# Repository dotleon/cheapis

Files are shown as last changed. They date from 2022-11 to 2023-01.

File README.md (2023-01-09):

# cheapis

v0.1 issues:
- most ubs cables cannot be plugged in when the pro micro is soldered in an usual way (upright, with the usually included pins), because of the top middle buttons. It has to be solderes upside down, flush with the keyboard pcb.
- not really an issue, but SOD-323 diodes are challenging to solder. They're also not the cheapest, although the difference is minuscule.

Cheapis was inspired by ferris and sweep.

It is the cheapest alternative to the above keyboards (that still has a PCB) as it is sub 100x100mm in size so it can be ordered for a very low price and it only needs one controller (Pro Micro or alternative).

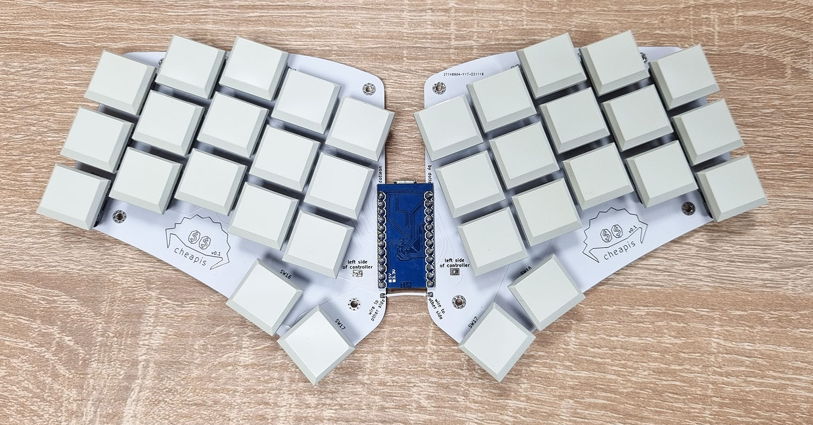
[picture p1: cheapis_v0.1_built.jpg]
cheapis keyboard! cheapis keyboard built


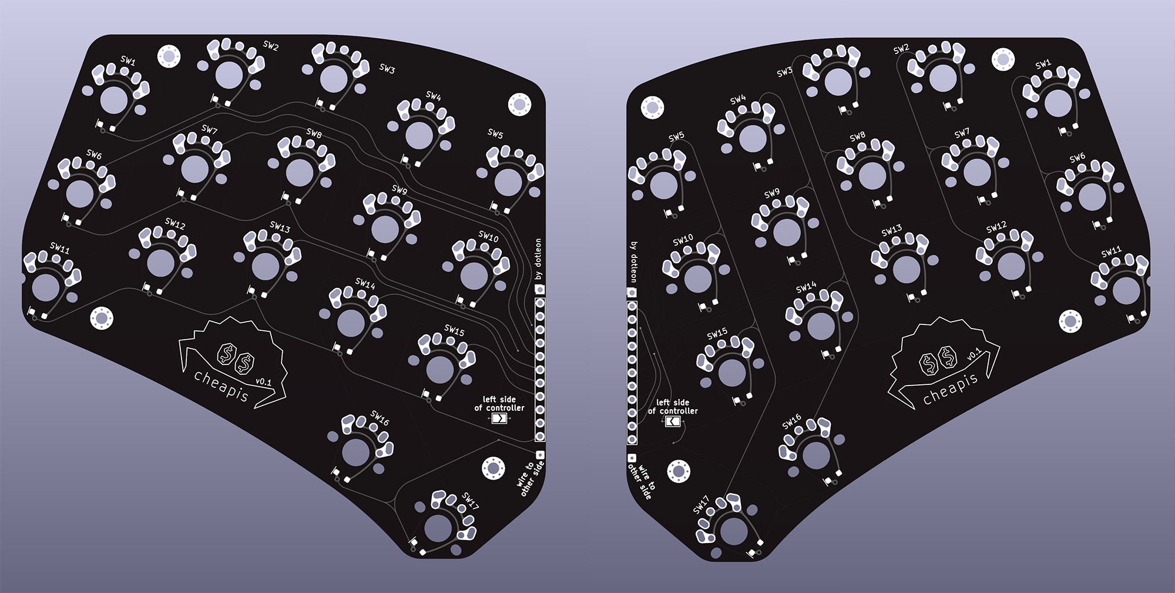
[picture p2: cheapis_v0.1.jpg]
cheapis keyboard! cheapis keyboard


Specs:
- Split
- Unibody
- 34 key
- Compatible with MX, Kailh Choc v1 and Gateron low profile switches
- needs 1n4148 SOD-323 diodes
- 19mm standard spacing
- angled sides by 20 degree

Pros:
- less than 100x100mm
- reversible, so you can order less
- needs ony one Pro Micro or alternative
- very cheap way to experiment with 34 key layout

Cons:
- it has to be unibody
- tenting is not possible
- fragile without a plate as the Pro Micro keeps the two sides together
- not much features, it's hardly more than a hardwire

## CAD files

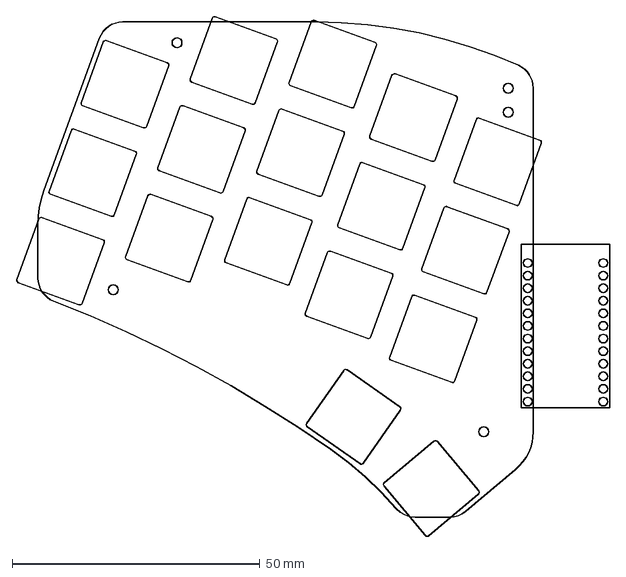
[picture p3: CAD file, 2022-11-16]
v0.1/design.dxf
119.6 x 104.9 mm

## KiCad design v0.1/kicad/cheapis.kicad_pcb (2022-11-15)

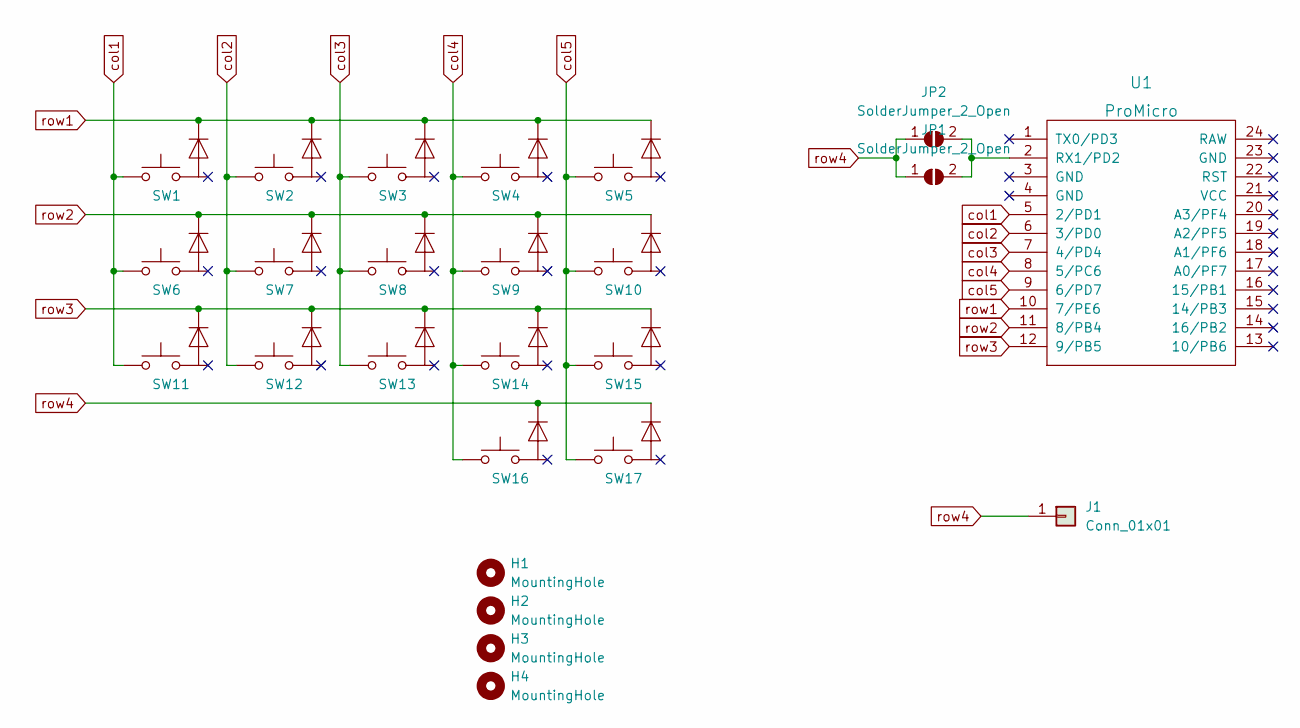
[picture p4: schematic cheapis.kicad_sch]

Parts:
H1, H2, H3, H4: MountingHole; MountingHole_2.2mm_M2_Pad_Via
J1: Conn_01x01; SolderWire-0.1sqmm_1x01_D0.4mm_OD1mm
JP1, JP2: SolderJumper_2_Open; SolderJumper-2_P1.3mm_Open_TrianglePad1.0x1.5mm
SW1, SW2, SW3, SW4, SW5, SW6, SW7, SW8, SW9, SW10, SW12, SW13, SW14, SW15, SW16, SW17: SW_Diode_Combined; SW_MX_GATLP_CHOC_reversible
SW11: SW_Diode_Combined; SW_MX_GATLP_CHOC_reversible_sideofpcb
U1: ProMicro; promicro_half

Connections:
unnamed: JP1.2 (B), JP2.2 (B), U1.2 (RX1/PD2)
col1: SW1.1, SW6.1, SW11.1, U1.5 (2/PD1)
col2: SW2.1, SW7.1, SW12.1, U1.6 (3/PD0)
col3: SW3.1, SW8.1, SW13.1, U1.7 (4/PD4)
col4: SW4.1, SW9.1, SW14.1, SW16.1, U1.8 (5/PC6)
col5: SW5.1, SW10.1, SW15.1, SW17.1, U1.9 (6/PD7)
row1: SW1.3, SW2.3, SW3.3, SW4.3, SW5.3, U1.10 (7/PE6)
row2: SW6.3, SW7.3, SW8.3, SW9.3, SW10.3, U1.11 (8/PB4)
row3: SW11.3, SW12.3, SW13.3, SW14.3, SW15.3, U1.12 (9/PB5)
row4: J1.1, JP1.1 (A), JP2.1 (A), SW16.3, SW17.3

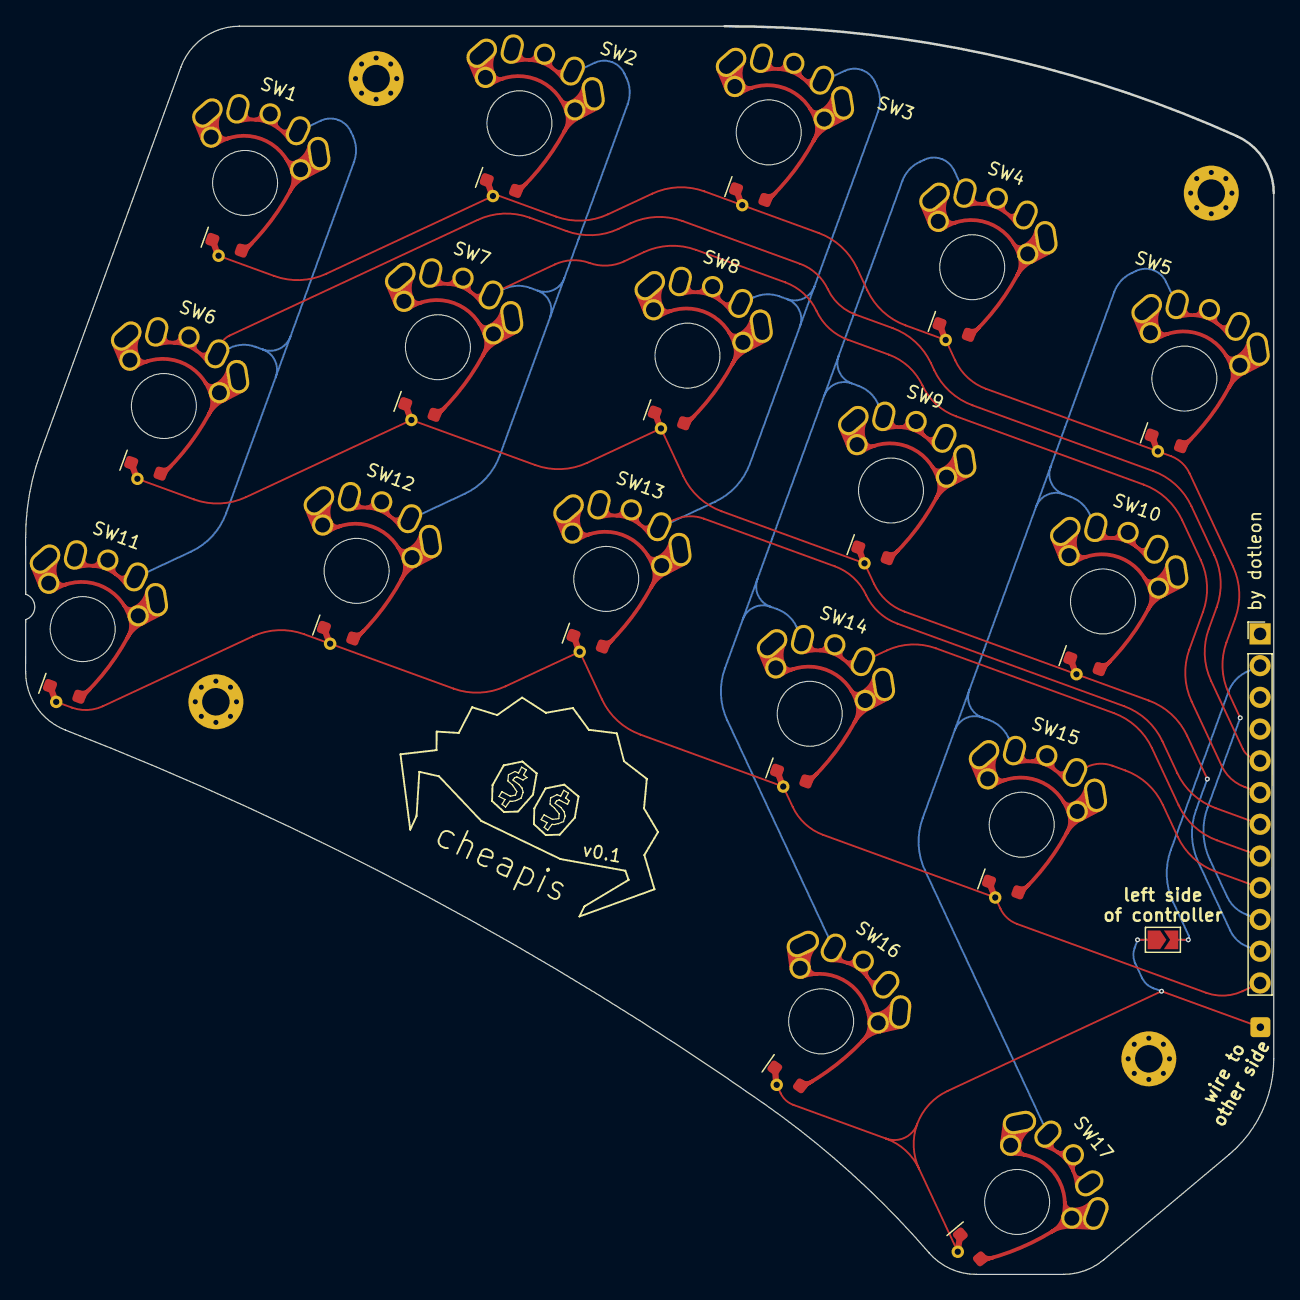
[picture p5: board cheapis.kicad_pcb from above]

Board: 2 copper layers, 99.9 x 99.9 mm, 25 parts (1 on the bottom side), 10 nets.

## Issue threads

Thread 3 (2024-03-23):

Build guide

ohri-anurag, 2024-03-23:
Hi there, thanks a lot for creating this keyboard! I've ordered parts for it, and I wanted to clarify some questions that I had:
1. Can I use Cherry low profile switches?
2. Could you upload another pic of the fully built keyboard, but one from the back? It would answer most questions that I have. I'm a bit confused about how to solder the MCU and diodes. If not a pic, then a line or two about orientation would help greatly.

dotleon, 2024-03-23:
Hey,

I'm a little bit ashamed that this got traction, as v0.1 is a little bit jank. In the future I'm planning on making a better version (better diode support, better ways to mount the controller).

1. As far as I know, Cherry MXLP has the same footprint as MX, so it should be fine.
2. Here I made a video for you about the controller, and the diodes go under the keys, where leds would go.
https://www.youtube.com/watch?v=thpRRhPbJ5U

ohri-anurag, 2024-03-23:
Thanks, that clarifies the questions I had about the MCU. When you say the diodes go under the keys, do you mean that both of them are soldered on the same side of the PCB?

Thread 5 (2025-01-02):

Question regarding the cable

thomas88100, 2025-01-02:
Hi,
I'm new in the world of split diy keyboards and I want to know what type of wire I can use to connect the two parts ? Is it just a simple electric wire ?

dotleon, 2025-01-02:
Hey,

Yes, you can use any electic wire. I've used wire salvaged from an ethernet cable.

Closed 2025-02-03.

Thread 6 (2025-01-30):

Would a diode-less design be possible?

ashok-arora, 2025-01-30:
Hey, thank you for the design! It is very neat. Since diodes are hard to solder and there are a lot of them, would a diode-less design be possible?

dotleon, 2025-01-30:
Not really, you would have to short the two pads where the diodes go. You might be able to do that with solder, but I usually struggle bridging even smaller distances.
A new version would be in order, with THT diode, diode-less, etc support, but as I didn't get into 34 keys, it's hard to find the motivation.

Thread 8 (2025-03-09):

Usb placement problem

Apiratchai, 2025-03-09:
Hello, I really like this project and also working on a fork that will use the Redragon low profile switch instead.

You stated in your reddit post that v0.2 will solve the usb placement problem, how would it look like ?

dotleon, 2025-03-09:
Hello.

There is a lot of extra empty space in the 100x100 rectangle (green) which could be used for an extra break-off part which would go between the two sides.
This would solve a couple of things:

- It could use more pins for better stability, especially because of having more than one column
- as you have two of these per keyboard, you could use both, one over and one under the pcb for even more stability
- the extra wire and the jumper pad wouldn't be necessary as the controller could be routed properly on this extra board
- but most importantly it would increase the distance between the two halves, therefore there would be enough space for the USB

One big disadvantage is that JLCPCB could recognize this as two designs and charge extra for it.

Here's what I imagined:

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

Apiratchai, 2025-03-09:
That’s a brilliant.
I’m wondering if we could route some open wires that don’t actually serve any purpose to the breakout part, just to trick them into thinking they’re part of the thumb cluster. It's similar to how the Corne 5x6 layout can be broken down into a 5x5 layout. The Corne uses M3 screw holes as a break point for that.

dotleon, 2025-03-09:
Yes! Routing some wires there could make it easier to argue that it's part of the same design.

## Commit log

2022-11-15 cheapis v0.1 added
    [cheapis.kicad_pcb, cheapis.kicad_sch, design.dxf]
2022-11-16 fixed pro micro location in the design.dxf of the v0.1
    [design.dxf]
2023-01-09 added picture of built v0.1 prototype, removed the line about how the prototype is on it's way, as it arrived
